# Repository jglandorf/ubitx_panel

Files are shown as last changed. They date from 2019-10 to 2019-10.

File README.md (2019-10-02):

### Wiring Harness PCB Panel for the µBITX  
The [µBITX](http://www.hfsignals.com/index.php/ubitx/) is "The QRP HF General Coverage Transceiver you can build".  
 * Speeds wiring to the µBITX mic, speaker, and keyer sockets, and encoder  
 * Encoder on breakaway PCB section allows for separate mounting location  
 * Reduces wiring errors  
 * Allows use of an inexpensive Baofeng speaker mic  
 * Easily mounts to an enclosure  
 * Schematic, PCB in [Kicad 5](http://www.kicad-pcb.org/download/)  

See [docs/ubitx_panel_usage.pdf](docs/ubitx_panel_usage.pdf) for a complete description.  
Used successfully for the [Arrow Communications Assn.](https://w8rp.org/) uBitx build sessions.  
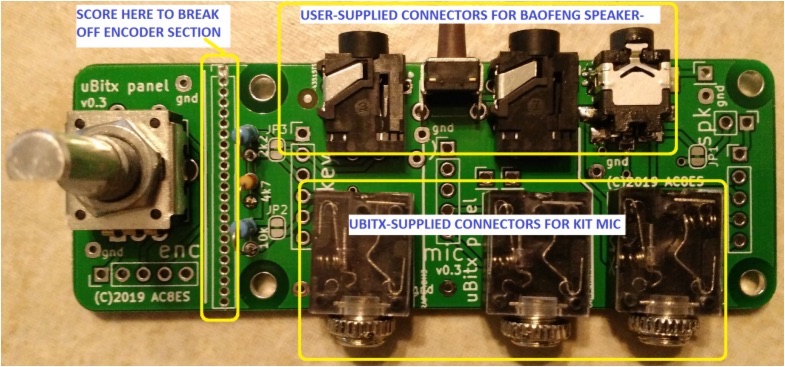
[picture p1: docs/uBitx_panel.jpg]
uBitx_panel
  
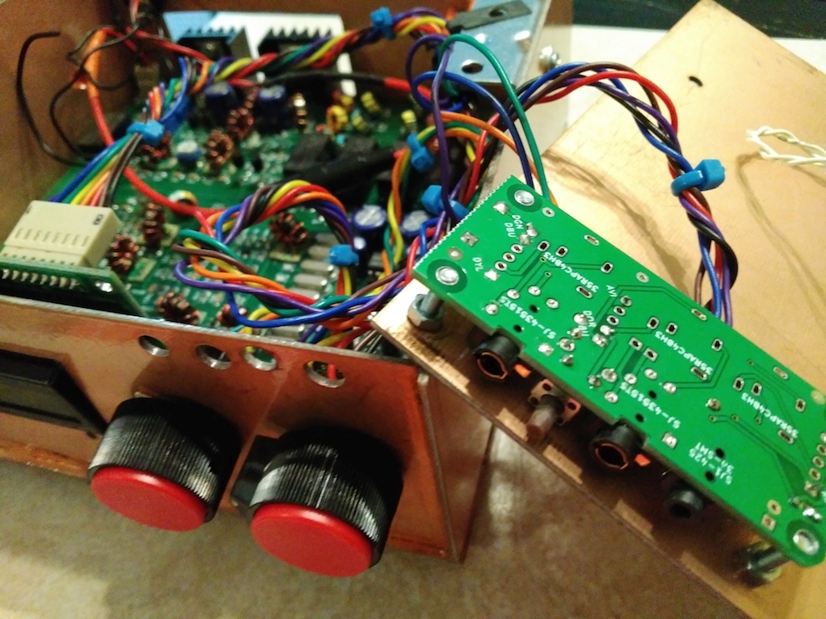
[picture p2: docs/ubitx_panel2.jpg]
uBitx_panel2
  
73
Joe, AC8ES

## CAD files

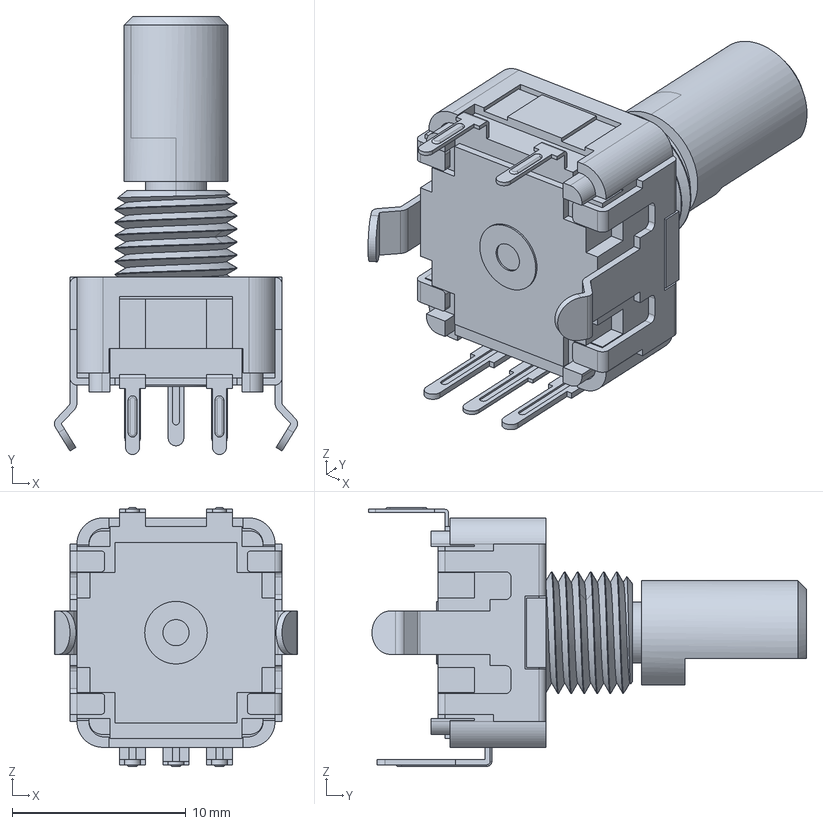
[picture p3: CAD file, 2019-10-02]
datasheets/pec11r-4x15f-sxxxx.stp
14.0 x 25.2 x 14.9 mm

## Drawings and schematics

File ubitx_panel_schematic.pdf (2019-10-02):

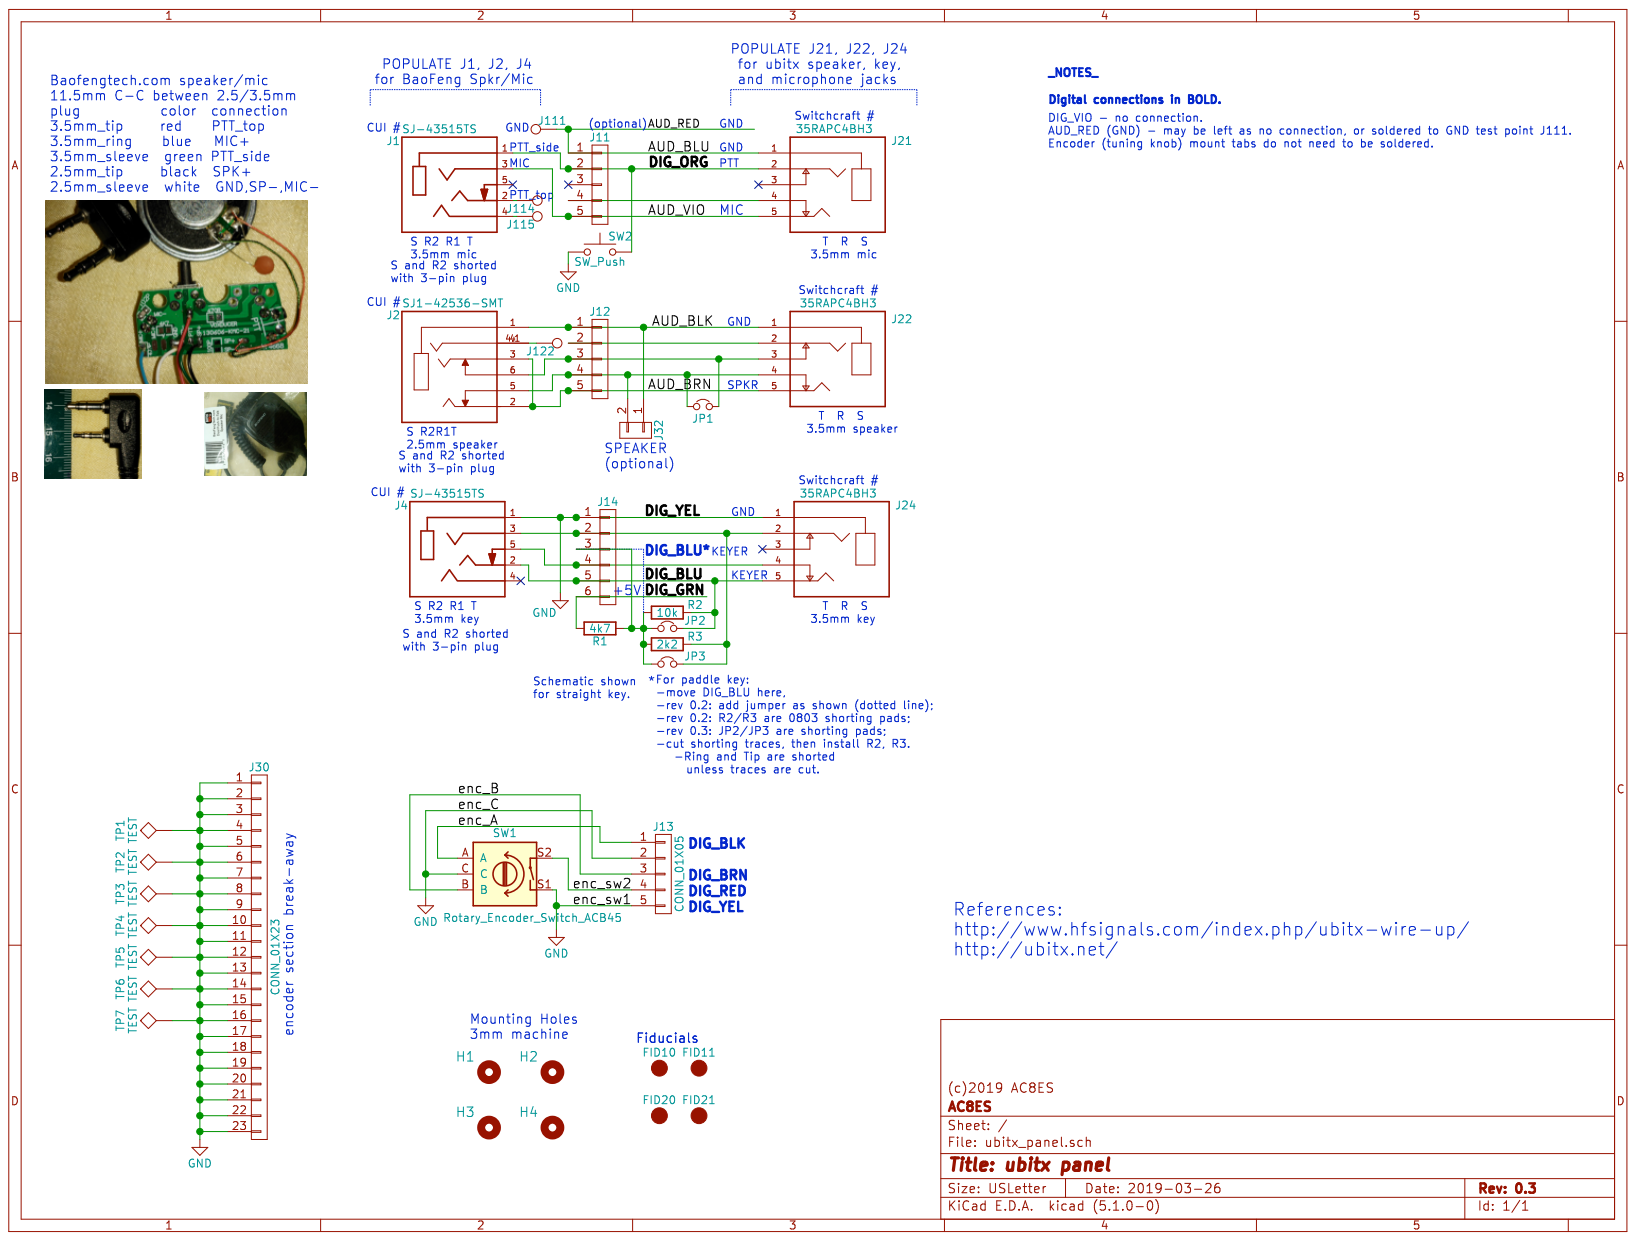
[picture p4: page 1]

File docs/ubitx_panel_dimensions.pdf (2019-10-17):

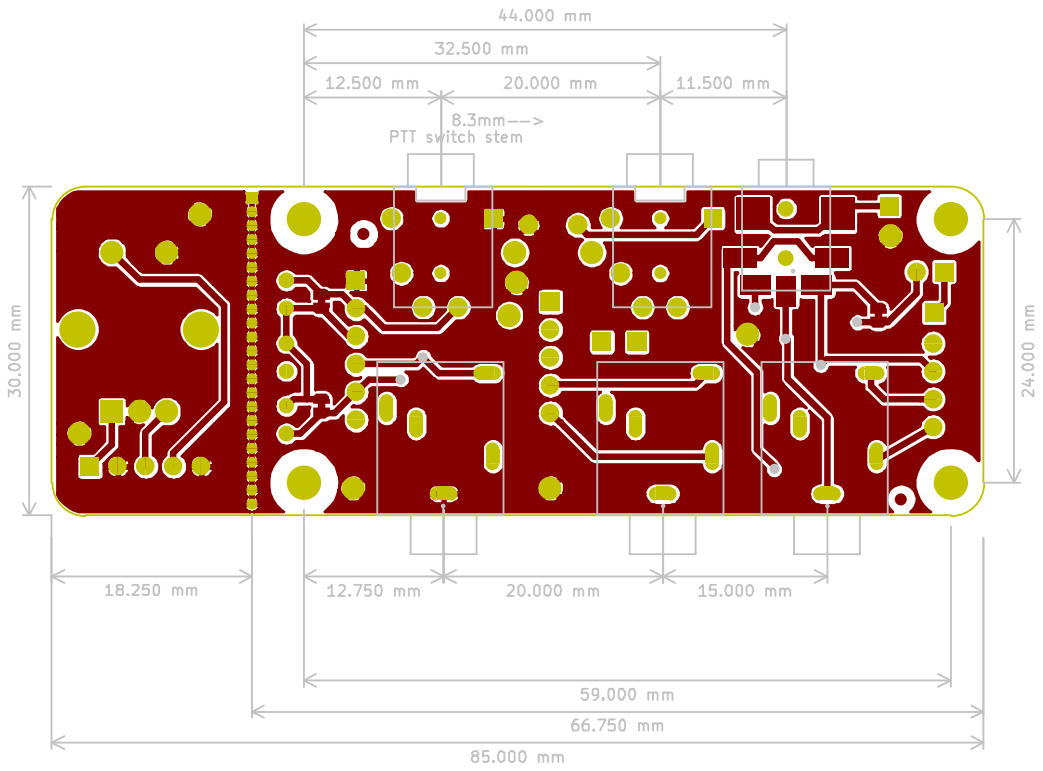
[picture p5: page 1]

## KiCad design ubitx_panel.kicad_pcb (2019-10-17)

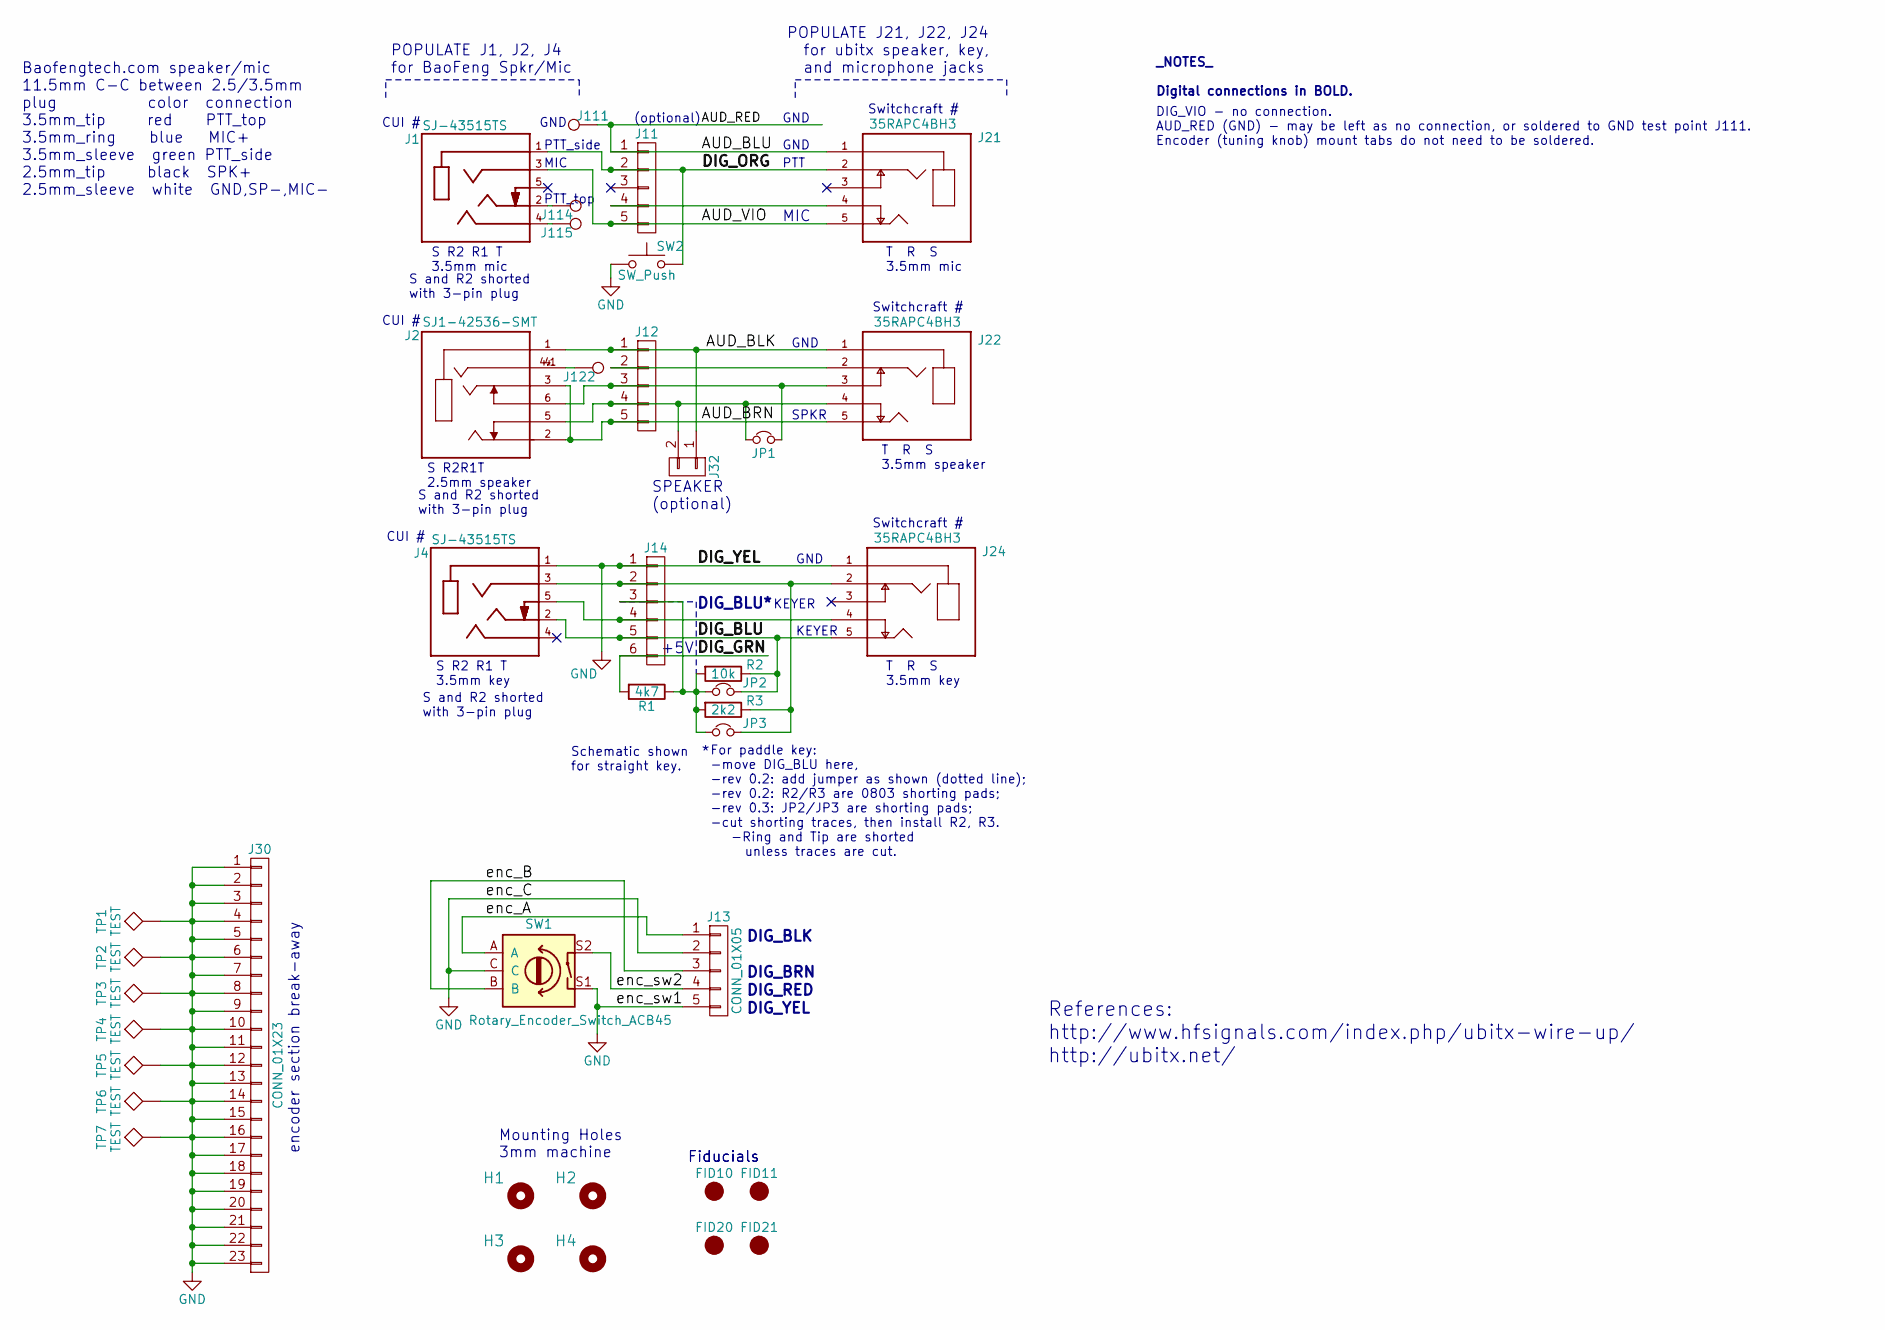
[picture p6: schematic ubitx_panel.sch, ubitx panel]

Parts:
FID10, FID11: CIRCLE1mmDia; Fiducial_1mm_Dia_2.54mm_Outer_CopperTop; MPN DNP
FID20, FID21: CIRCLE1mmDia; Fiducial_1mm_Dia_2.54mm_Outer_CopperBottom; MPN DNP
H1, H2: 3mm_Mounting_Hole; NPTH_3mm_ID; MPN DNP
H3, H4: 3mm_Mounting_Hole_Unlocked; NPTH_3mm_ID_Unlocked; MPN DNP
J1, J4: SJ-43515TS; CUI_SJ-43515TS
J2: SJ1-42536-SMT; CUI_SJ1-42536-SMT-move4
J11, J12, J13: CONN_01X05; Pin_Header_Straight_1x05_Pitch2.54mm
J14: CONN_01X06; Pin_Header_Straight_1x06_Pitch2.54mm
J21, J22, J24: 35RAPC4BH3; SWITCHCRAFT_35RAPC4BH3
J30: CONN_01X23; Pin_Header_Straight_1x23_Pitch1.27mm
J32: CONN_01X02; Pin_Header_Straight_1x02_Pitch2.54mm
J111: TEST_1P; SolderWirePad_single_0-8mmDrill
J114, J115, J122: TEST_1P; Socket_Strip_Straight_1x01_Pitch2.54mm
JP1, JP2, JP3: Jumper_NC_Small; SolderJumper-2_P1.3mm_Bridged_RoundedPad1.0x1.5mm
R1: 4k7; R_Axial_DIN0204_L3.6mm_D1.6mm_P2.54mm_Vertical
R2: 10k; R_Axial_DIN0204_L3.6mm_D1.6mm_P2.54mm_Vertical
R3: 2k2; R_Axial_DIN0204_L3.6mm_D1.6mm_P2.54mm_Vertical
SW1: Rotary_Encoder_Switch_ACB45; RotaryEncoder_Alps_EC11E-Switch_Vertical_H20mm_CircularMoun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; MPN PEC11R-4015F-S0024
SW2: SW_Push; SW_Tactile_SPST_Angled
TP1, TP2, TP3, TP4, TP5, TP6, TP7: TEST; SolderWirePad_single_0-8mmDrill

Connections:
/AUD_BLK: J2.1, J12.1, J22.1, J32.1
/AUD_BLU: J11.1, J21.1, J111.1
/AUD_BRN: J2.2, J2.3, J12.5, J22.5
/AUD_VIO: J1.3 (RING1), J11.5, J21.5
/DIG_BLU: J4.2 (TIP), J14.5, J24.5, JP2.2, R2.1
/DIG_GRN: J14.6, R1.2
/DIG_ORG: J1.1 (SLEEVE), J11.2, J21.2, SW2.2
/enc_A: J13.1, SW1.A
/enc_B: J13.3, SW1.B
/enc_sw2: J13.4, SW1.S2
GND: J4.1 (SLEEVE), J13.2, J13.5, J14.1, J24.1, J30.1, J30.2, J30.3, J30.4, J30.5, J30.6, J30.7, J30.8, J30.9, J30.10, J30.11, J30.12, J30.13, J30.14, J30.15, J30.16, J30.17, J30.18, J30.19, J30.20, J30.21, J30.22, J30.23, SW1.C, SW1.S1, SW2.1, TP1.1, TP2.1, TP3.1, TP4.1, TP5.1, TP6.1, TP7.1
unnamed: J1.2 (TIP), J114.1
unnamed: J1.4 (RING2), J115.1
unnamed: J11.4, J21.4
unnamed: J12.2, J22.2
unnamed: J2.6, J12.3, J22.3, JP1.2
unnamed: J2.5, J12.4, J22.4, J32.2, JP1.1
unnamed: J4.3 (RING1), J14.2, J24.2, JP3.2, R3.1
unnamed: J14.3, JP2.1, JP3.1, R1.1, R2.2, R3.2
unnamed: J4.5 (TIP_SWITCH), J14.4, J24.4
unnamed: J2.4, J2.4.1 (4), J122.1

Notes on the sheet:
Mounting Holes 3mm machine
Fiducials
S R2 R1 T 3.5mm mic
T R S 3.5mm mic
T R S 3.5mm speaker
S R2R1T 2.5mm speaker
S R2 R1 T 3.5mm key
T R S 3.5mm key
DIG_RED
DIG_YEL
DIG_BLK
DIG_BRN
Baofengtech.com speaker/mic 11.5mm C-C between 2.5/3.5mm plug color connection 3.5mm_tip red PTT_top 3.5mm_ring blue MIC+ 3.5mm_sleeve green PTT_side 2.5mm_tip black SPK+ 2.5mm_sleeve white GND,SP-,MIC-
S and R2 shorted with 3-pin plug
MIC
PTT
GND
SPKR
PTT_side
PTT_top
encoder section break-away
POPULATE J1, J2, J4 for BaoFeng Spkr/Mic
POPULATE J21, J22, J24 for ubitx speaker, key, and microphone jacks
References: http://www.hfsignals.com/index.php/ubitx-wire-up/ http://ubitx.net/
SPEAKER (optional)
KEYER
_NOTES_ Digital connections in BOLD.
(optional)
DIG_VIO - no connection. AUD_RED (GND) - may be left as no connection, or soldered to GND test point J111. Encoder (tuning knob) mount tabs do not need to be soldered.
CUI #
+5V
Switchcraft #
DIG_BLU*
Schematic shown for straight key.
For paddle key: -move DIG_BLU here, -rev 0.2: add jumper as shown (dotted line); -rev 0.2: R2/R3 are 0803 shorting pads; -rev 0.3: JP2/JP3 are shorting pads; -cut shorting traces, then install R2, R3. -Ring and Tip are shorted unless traces are cut.

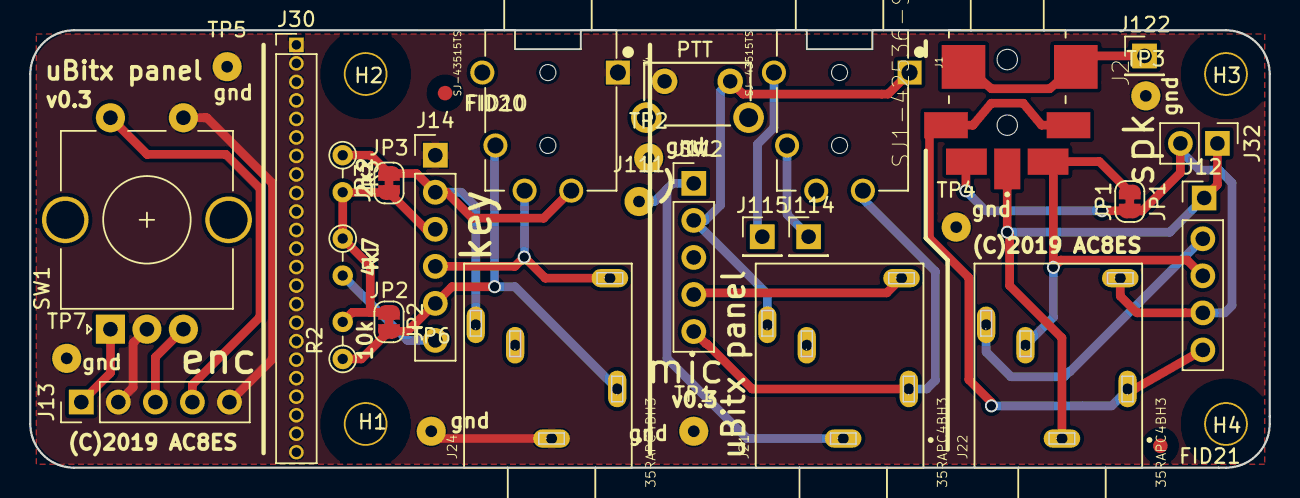
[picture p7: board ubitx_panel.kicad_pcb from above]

Board: 2 copper layers, 85.0 x 30.0 mm, 39 parts (0 on the bottom side), 21 nets.

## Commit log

2019-10-02 Wiring Harness PCB Panel for the µBITX
    A Wiring Harness PCB Panel for the µBITX.
    [pec11r-4x15f-sxxxx.stp, ubitx_panel-2019-03-19-20-56-45.sch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]
2019-10-17 Added dimensions for mounting
    Added dimensions for mounting holes, board outline, and connector centerline spacing.
    [ubitx_panel.kicad_pcb]

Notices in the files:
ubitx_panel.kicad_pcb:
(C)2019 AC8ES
